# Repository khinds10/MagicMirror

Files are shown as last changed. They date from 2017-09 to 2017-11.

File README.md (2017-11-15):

# Magic Mirror
#### Wall Based Magic Mirror for Current Weather & Time

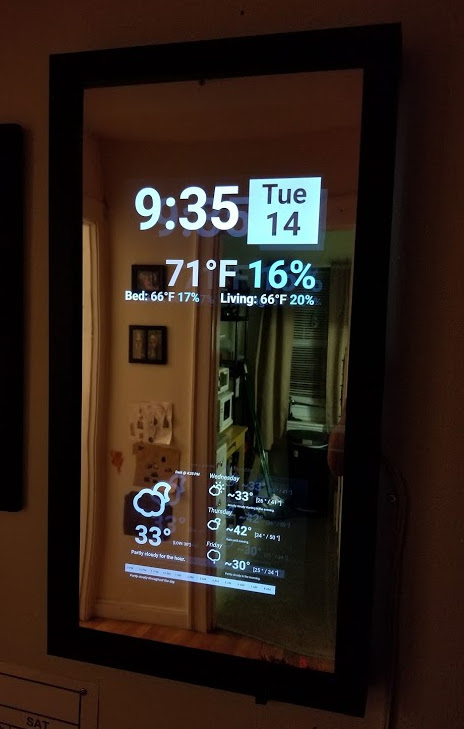
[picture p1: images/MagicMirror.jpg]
Magic Mirror


#### Flashing RaspberriPi Hard Disk / Install Required Software (Using Ubuntu Linux)

Download "RASPBIAN JESSIE LITE"
https://www.raspberrypi.org/downloads/raspbian/

**Create your new hard disk for DashboardPI**
>Insert the microSD to your computer via USB adapter and create the disk image using the `dd` command
>
> Locate your inserted microSD card via the `df -h` command, unmount it and create the disk image with the disk copy `dd` command
> 
> $ `df -h`
> */dev/sdb1       7.4G   32K  7.4G   1% /media/XXX/1234-5678*
> 
> $ `umount /dev/sdb1`
> 
> **Caution: be sure the command is completely accurate, you can damage other disks with this command**
> 
> *if=location of RASPBIAN JESSIE LITE image file*
> *of=location of your microSD card*
> 
> $ `sudo dd bs=4M if=/path/to/raspbian-jessie-lite.img of=/dev/sdb`
> *(note: in this case, it's /dev/sdb, /dev/sdb1 was an existing factory partition on the microSD)*

**Setting up your RaspberriPi**

*Insert your new microSD card to the raspberrypi and power it on with a monitor connected to the HDMI port*

Login
> user: **pi**
> pass: **raspberry**

Change your account password for security
>`sudo passwd pi`

Enable RaspberriPi Advanced Options
>`sudo raspi-config`

Choose:
`1 Expand File System`

`9 Advanced Options`
>`A2 Hostname`
>*change it to "MagicMirror"*
>
>`A4 SSH`
>*Enable SSH Server*
>
>`A7 I2C`
>*Enable i2c interface*

**Enable the English/US Keyboard**

>`sudo nano /etc/default/keyboard`

> Change the following line:
>`XKBLAYOUT="us"`

**Reboot PI for Keyboard layout changes / file system resizing to take effect**
>$ `sudo shutdown -r now`

**Auto-Connect to your WiFi**

>`sudo nano /etc/wpa_supplicant/wpa_supplicant.conf`

Add the following lines to have your raspberrypi automatically connect to your home WiFi
*(if your wireless network is named "linksys" for example, in the following example)*

	network={
	   ssid="linksys"
	   psk="WIRELESS PASSWORD HERE"
	}

**Reboot PI to connect to WiFi network**

>$ `sudo shutdown -r now`
>
>Now that your PI is finally on the local network, you can login remotely to it via SSH.
>But first you need to get the IP address it currently has.
>
>$ `ifconfig`
>*Look for "inet addr: 192.168.XXX.XXX" in the following command's output for your PI's IP Address*

**Go to another machine and login to your raspberrypi via ssh**

> $ `ssh pi@192.168.XXX.XXX`

**Start Installing required packages**

>$ `sudo apt-get update`
>
>$ `sudo apt-get upgrade`
>
>$ `sudo apt-get install vim git python-smbus i2c-tools python-imaging python-smbus build-essential python-dev rpi.gpio python3 python3-pip libi2c-dev python-requests`

**Update local timezone settings**

>$ `sudo dpkg-reconfigure tzdata`

> select your timezone using the interface

**Setup the simple directory `l` command [optional]**

>$ `vi ~/.bashrc`
>
>*add the following line:*
>
>$ `alias l='ls -lh'`
>
>$ `source ~/.bashrc`

**Fix VIM default syntax highlighting [optional]**

>$ `sudo vi /etc/vim/vimrc`
>
>uncomment the following line:
>
>_syntax on_

**DHT11 Install**

>$ `cd ~`
>
>$ `git clone https://github.com/adafruit/Adafruit_Python_DHT.git`
>
>$ `cd Adafruit_Python_DHT/`
>
>$ `sudo python setup.py install`
>
>$ `sudo python ez_setup.py`
>
>$ `cd examples/`
>
>$ `vi simpletest.py`
>

Change the following line:
> sensor = Adafruit_DHT.DHT11

Comment the line out
> pin = 'P8_11'

Uncomment the line and change the pin number to 16
> pin = 16

Run the test

`python simpletest.py`

> You should see a metric reading of Temp and Humidity displayed on the command line.

## Supplies Needed

**12" x 24" Acrylic See-Through Mirror, 3mm**

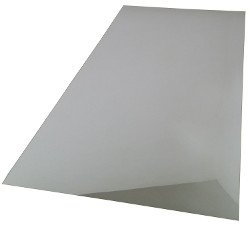
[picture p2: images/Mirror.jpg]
Mirror


**Balsa wood strips 0.125 x 0.5 Inches**

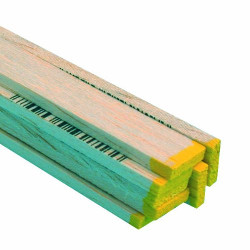
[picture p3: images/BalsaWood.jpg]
Balsa Wood


**12x24 inch Black Picture Frame**

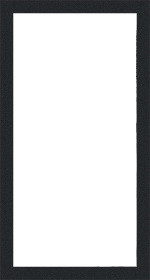
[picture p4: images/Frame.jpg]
Frame


**Android Tablets (x2)**

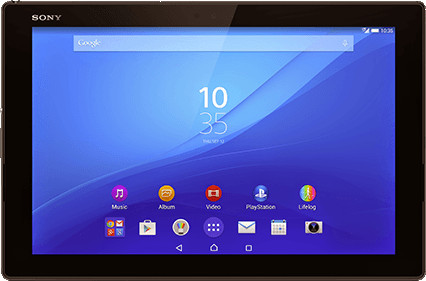
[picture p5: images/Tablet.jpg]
Tablet


**DHT11 Humidistat**

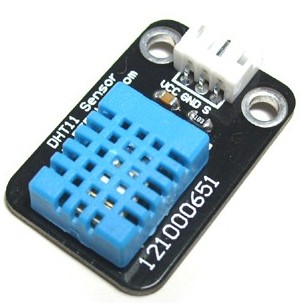
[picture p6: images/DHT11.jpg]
DHT11


**RaspberriPi Zero (or Regular RaspberriPi should work)**

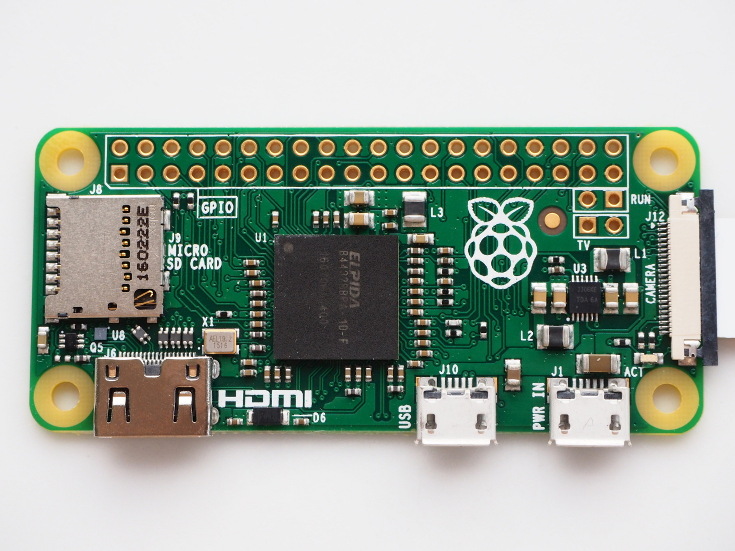
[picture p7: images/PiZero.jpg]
PiZero


## Build and wire the device

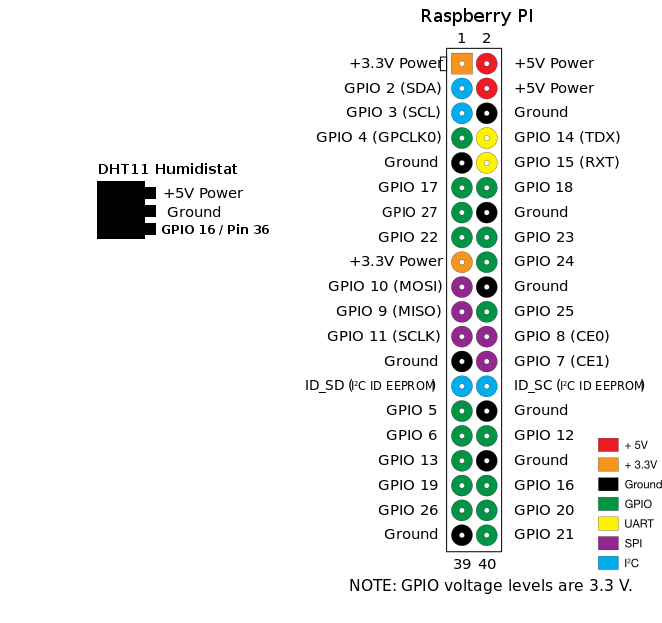
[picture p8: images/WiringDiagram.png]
Wiring Diagram

    
**DHT11 Humidistat**

> VCC -> 5V
>
> GND -> GND
>
> DATA -> GPIO 16 / PIN 36
>

### 3D Print

In the **/construction** folder of the project 3D print the following attachments to build the picture frame borders and tablet holders.

**Print the Following Tablet Holders:**

tablet-mounts.stl

**Print the Following Frame Corner blocks and balsa wood attachments:**

mirror-corner-blocks.stl

mirror-corners.stl

mirror-sides.stl

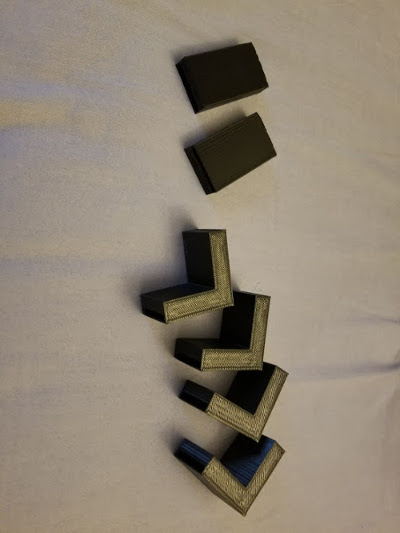
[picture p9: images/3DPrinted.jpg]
3D Printed


### Assembly

Gather together the frame balsa wood strips and the 3D printed attachments

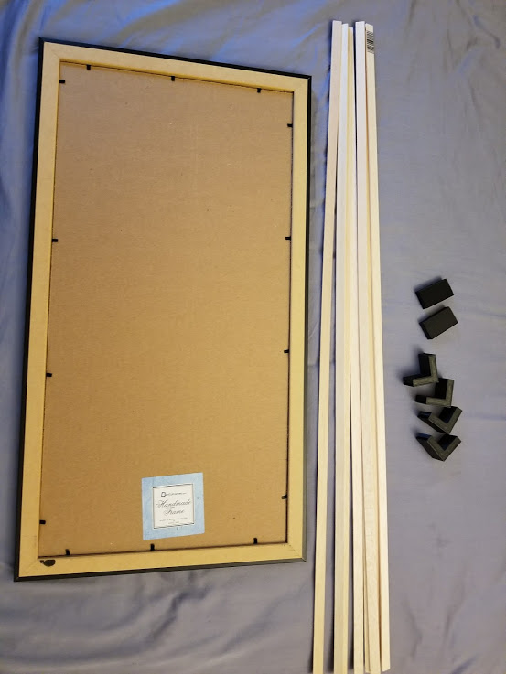
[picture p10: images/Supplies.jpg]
Supplies


Assemble the balsawood strips inside the corner brackets (sliding the balsawood through the side brackets, make sure they're square against the corners of the picture frame.  Paint everything black with spray paint.

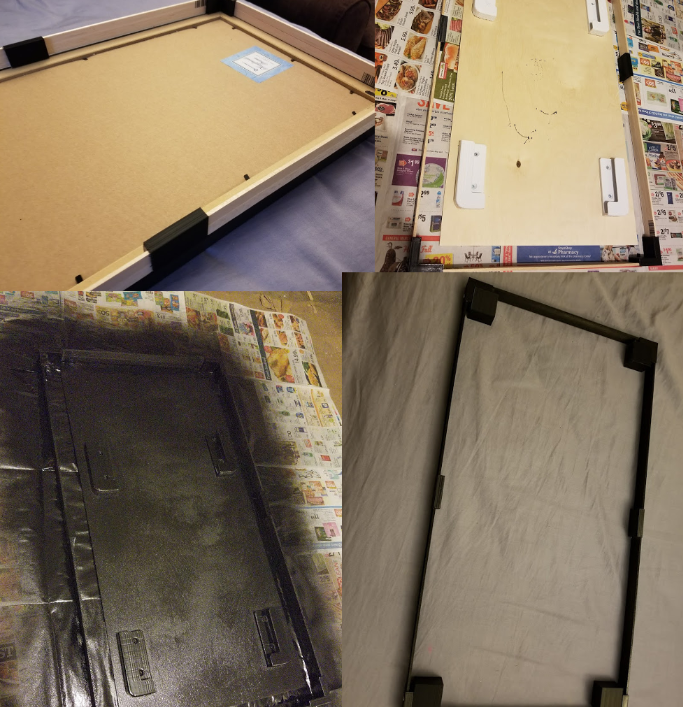
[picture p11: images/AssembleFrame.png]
Assemble Frame


Screw the corners to the 4 corner blocks to hold the frame together.
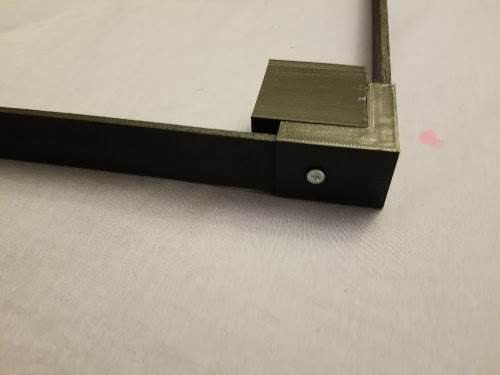
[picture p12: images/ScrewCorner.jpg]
Screw Corners


Attach the tablets and Raspberry PiZero to the wood to eventually fix to the wall. 

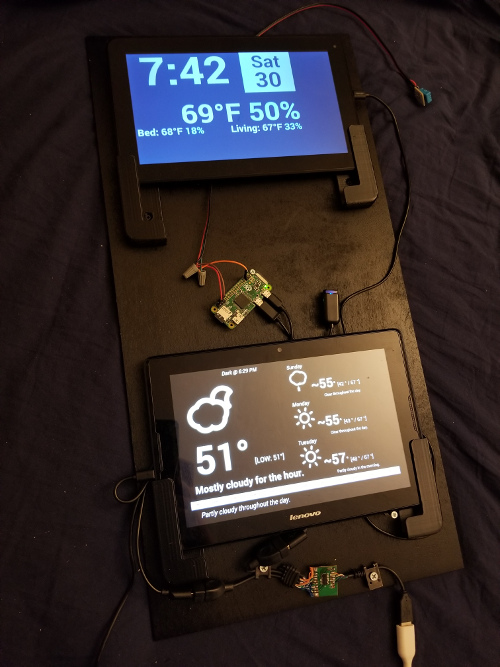
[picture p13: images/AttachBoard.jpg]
Attach Board


Attach to the wall the board. *(Note the 2 screws on the top left and right, they will be used to hold up the picture frame with frame border attached to place in front of the tablets to shine through the mirror)*

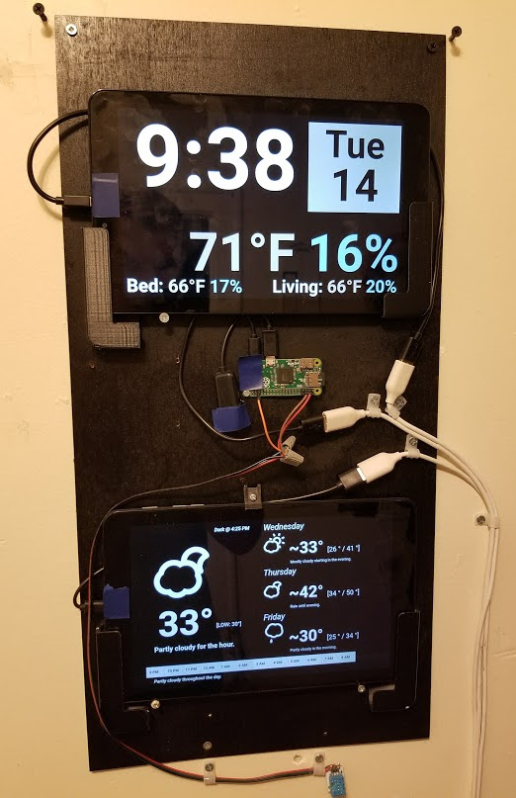
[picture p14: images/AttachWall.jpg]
Attach Wall


Finally replace the cardboard piece inside the picture frame with a two way mirror and on each corner of the picture frame screw into the corner *(3D printed)* blocks to hold the picture frame to the frame border.

Magic Mirror

## Create the Device Hub Project hosted on a PHP enabled webhost of your choice for the top tablet to get data

https://github.com/khinds10/DeviceHub

## Create Weather Tablet Project for the bottom tablet 

https://github.com/khinds10/WeatherTablet

## Setup Startup Scripts, Temp Logger to API script each 3 minutes

In the `raspberrypi` folder of the project copy the `settings.shadown.py` file to `settings.py` with the host file of the DeviceHub project above you have setup.

>$ `crontab -e`

Add the following lines:

`*/3 * * * * python /home/pi//MagicMirror/raspberrypi/temp-check.py`

Verify the display starts working on reboot

>$ `sudo reboot`

## Create the tablet clock website

Create a PHP enabled website online with the contents of the "tablet" folder in this project.

Configure the website:
  In the "**tablet/server**" folder of the project, copy the config.shadow.php file to a file named "**config.php**"
  Edit the "**config.php**" configure the $deviceHubAPI value to point to the device hub of your choosing from the referenced project above (https://github.com/khinds10/DeviceHub)

Example Apache2 Configuration File for the tablet clock PHP website

<VirtualHost *:80>
DocumentRoot /var/www/tablet
ServerName myclocktablet.com
ServerAdmin webmaster@myclocktablet.com
ErrorLog ${APACHE_LOG_DIR}/error-clock-tablet.log
CustomLog ${APACHE_LOG_DIR}/access-clock-tablet.log combined
<Directory /var/www/tablet>
Options FollowSymLinks
AllowOverride All
Require all granted
</Directory>
</VirtualHost>

**FINISHED!**

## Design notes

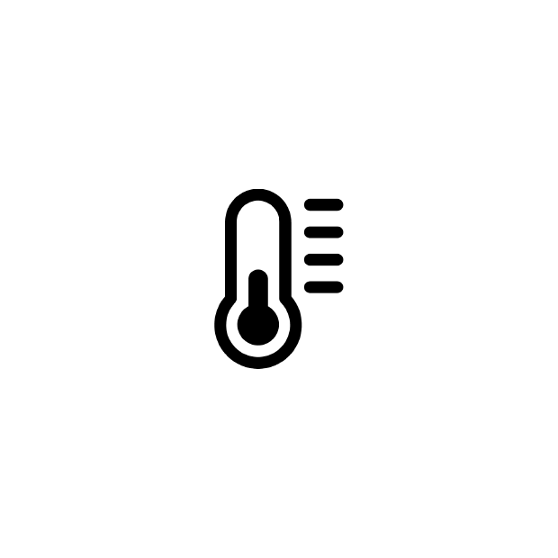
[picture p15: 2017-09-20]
tablet/img/tile.png

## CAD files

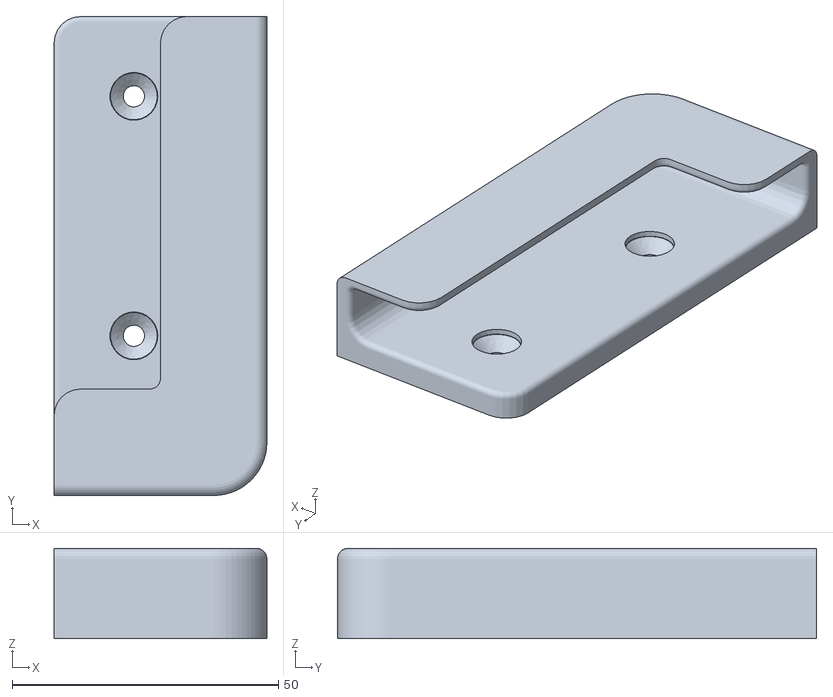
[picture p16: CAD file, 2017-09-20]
construction/3d-print-tablet-mounts/files/tabletMountRight.stl
40.0 x 90.0 x 17.0

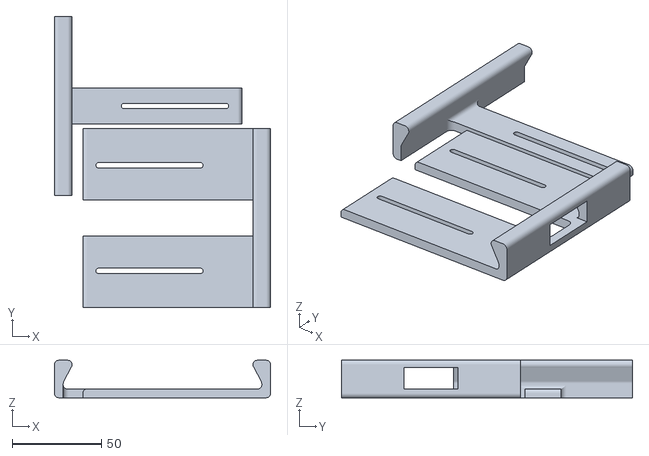
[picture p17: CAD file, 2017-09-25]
construction/tablet-mounts.stl
121.0 x 162.7 x 21.0

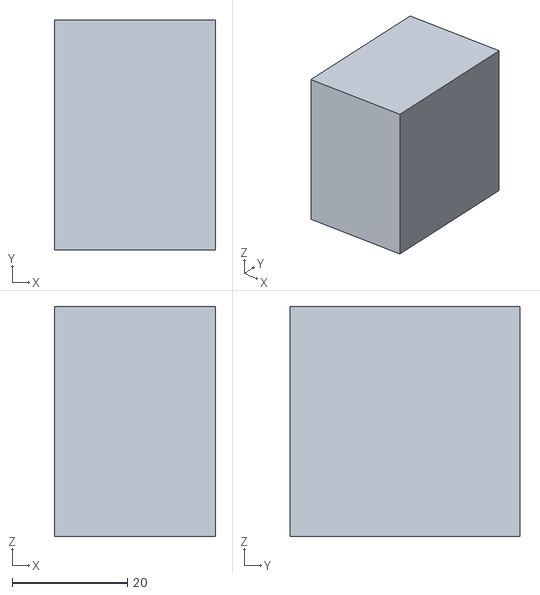
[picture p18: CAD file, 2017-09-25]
construction/mirror-corner-blocks.stl
28.0 x 40.0 x 40.0

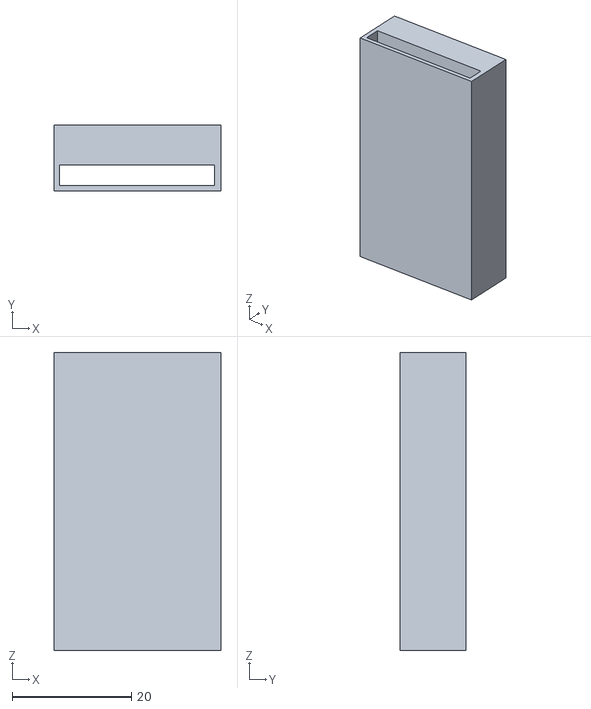
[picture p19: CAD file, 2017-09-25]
construction/mirror-sides.stl
28.0 x 11.1 x 50.0

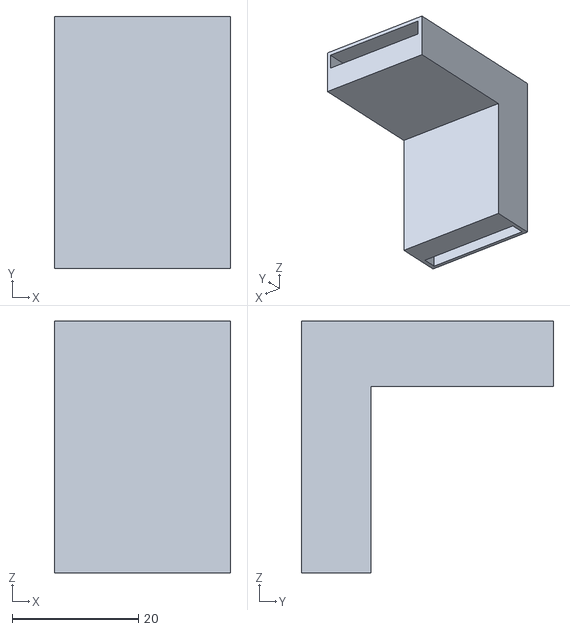
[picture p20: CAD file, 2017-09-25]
construction/mirror-corners.stl
28.0 x 40.0 x 40.0

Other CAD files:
construction/3d-print-tablet-mounts/files/tabletMountLeft.stl
construction/mirror-corners.blend

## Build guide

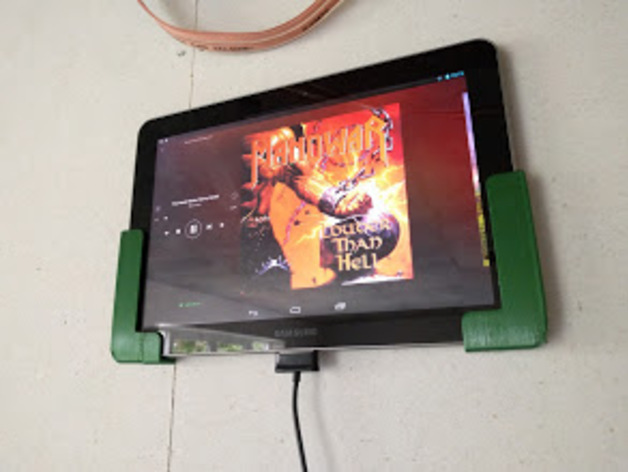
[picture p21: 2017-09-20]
construction/3d-print-tablet-mounts/images/a5cf27d2335538c91af3a0c7a81bfedf_preview_featured.jpg

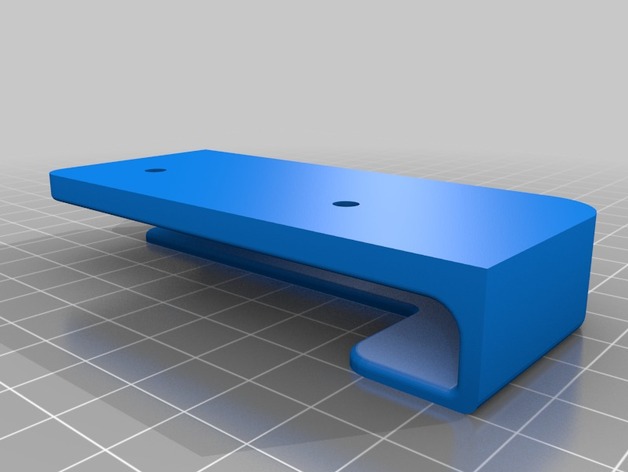
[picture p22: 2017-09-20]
construction/3d-print-tablet-mounts/images/f9a5fce7539ee55b7ab60ca0132f502a_preview_featured.jpg

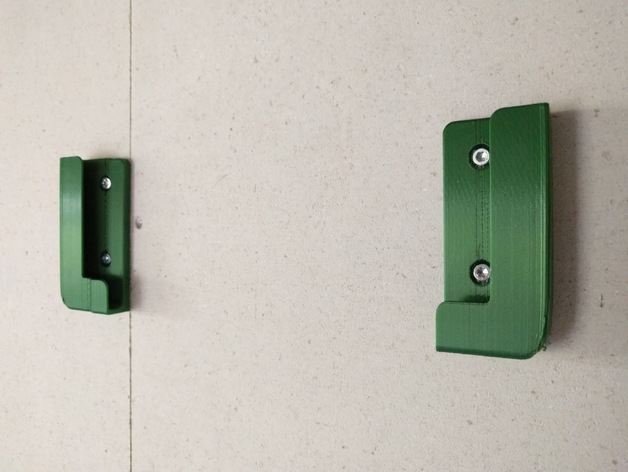
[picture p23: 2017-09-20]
construction/3d-print-tablet-mounts/images/4e6f731e2df180d50f8d5287468714ba_preview_featured.jpg

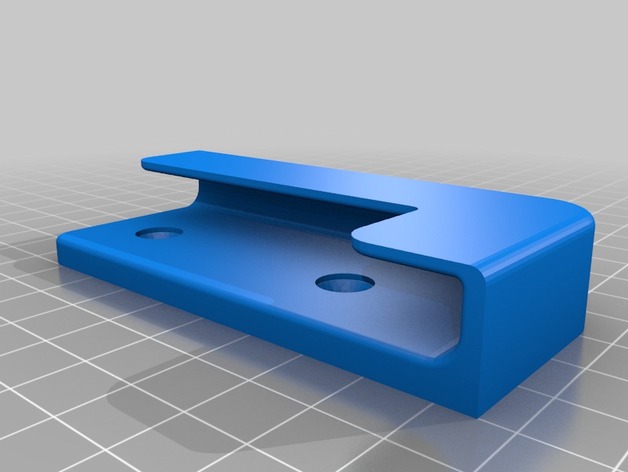
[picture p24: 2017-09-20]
construction/3d-print-tablet-mounts/images/fcdf374bd409c95d664282a9fb1f8aca_preview_featured.jpg

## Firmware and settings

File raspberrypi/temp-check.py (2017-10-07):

#!/usr/bin/python
# Kevin Hinds http://www.kevinhinds.com
# License: GPL 2.0
import datetime as dt
import time, json, string, cgi, subprocess, json
import settings as settings
import Adafruit_DHT
import pprint
pp = pprint.PrettyPrinter(indent=4)
import requests

# Raspberry Pi with DHT sensor - connected to GPIO16 / Pin 36
sensor = sensor = Adafruit_DHT.DHT11
pin = 16

# get current date and time
date=dt.datetime.now()

# get 10 readings and average, in case the humidistat is inaccurate
count, readingCount, avgTemperature, avgHumidity = [ 0, 0, 0, 0 ]
while (count < 10):
    humidity, temperature = Adafruit_DHT.read_retry(sensor, pin)
    print humidity
    print temperature

    if humidity is not None and temperature is not None:
        avgTemperature = avgTemperature + temperature
        avgHumidity = avgHumidity + humidity
        readingCount = readingCount + 1
    count = count + 1
avgTemperature = avgTemperature / readingCount
insideTemperature = int(avgTemperature * 9/5 + 32)
avgHumidity = avgHumidity / readingCount
insideHumidity = int(avgHumidity)

# post to datahub
r = requests.post("http://" + settings.deviceLoggerAPI + "/api/log/", data={'device': 'magic-mirror', 'value1': str(insideTemperature), 'value2': str(insideHumidity)})
print(r.status_code, r.reason)
print(r.text)

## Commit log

2017-09-20 setup project to be stand alone tablet and RPi for indoor tempuratures project
    [tabletMountLeft.stl, tabletMountRight.stl]
2017-09-23 fix project to only be indoor environment website, add supplies needed images
    [tabletMountLeft.stl, tabletMountRight.stl]
2017-09-25 added STL files for printing, finished up having the clock tablet site work by connecting to the devicehub project
    [mirror-corner-blocks.stl, mirror-corners.blend, mirror-corners.stl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]
2018-11-15 added new temperature readings
